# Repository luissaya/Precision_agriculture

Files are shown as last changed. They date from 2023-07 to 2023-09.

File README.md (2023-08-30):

# Precision Agriculture
Design of an IoT device for agriculture properties tracking.  
[Sensors](./docs/sensors.md)
## General Structure
The hole system is designed in two parts, the first is one *Gateway* that upload data to the cloud and the second is the *Node*. Various Nodes can feed the gateway with data from sensors.  
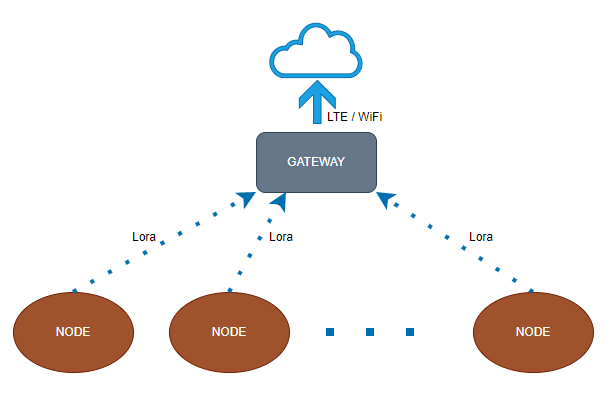
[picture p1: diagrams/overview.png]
overview

## Gateway
Receive the data from the Node and is preprocessed to be sent to the cloud through LTE, Ethernet or WiFi.
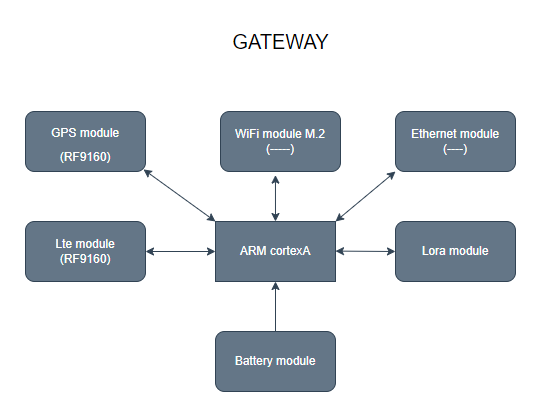
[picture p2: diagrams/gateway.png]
gateway

## [Node](./docs/Node.md)
Retrieve the data from sensors and send through Lora to the Gateway.
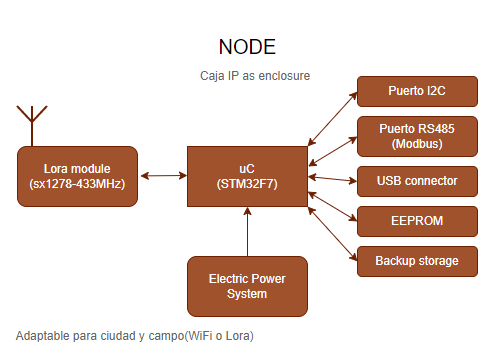
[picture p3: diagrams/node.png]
node
  
Note: *for indoor independent functionality the Lora module would be replaced for an WiFi module.*

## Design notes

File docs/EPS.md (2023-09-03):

# Electrical Power system
Design reference: [Quetzal](https://github.com/Quetzal-1-CubeSat-Team/quetzal1-hardware/tree/master/EPS)  
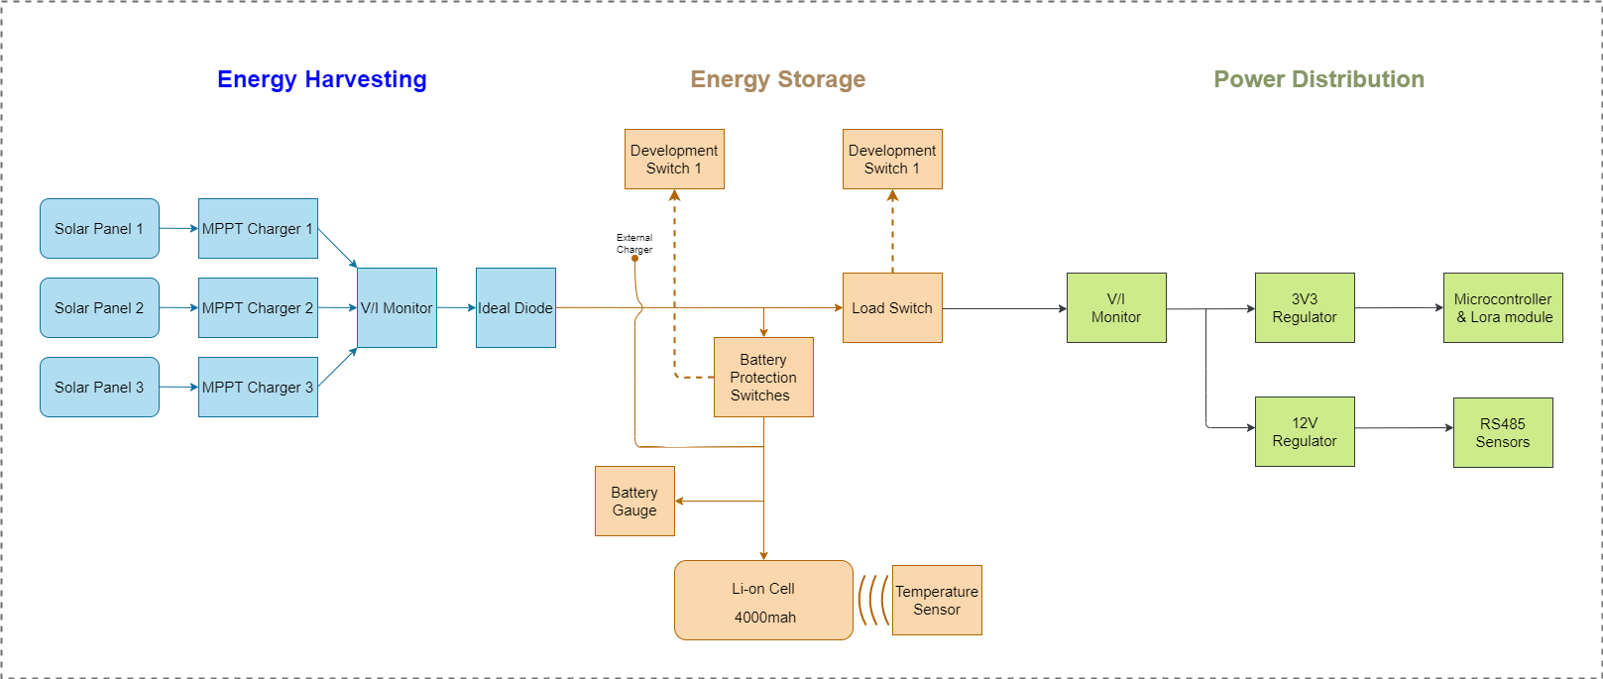
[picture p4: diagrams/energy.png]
energy
  
## Energy harvesting
* MPTT charger: for solar panels
* Voltage current monitor: for solar panels
* Ideal diode: supply current to *Energy storage*
  - Device: TC4352IMS#TRPBF - Low Voltage Ideal Diode Controller with Monitoring
  
## Energy storage
* Battery protection: limit current from solar panels
  - Device: TPS2551QDBVRQ1 - ADJUSTABLE CURRENT LIMITED POWER DISTRIBUTION SWITCH
* Battery monitoring: sense current from solar panels
  - Device: BQ27441DRZR-G1A - System-Side Impedance Track™ Fuel Gauge
  - operates with supplies from 2.9V to 18V
* Voltage protection: limit current that supply *Power distribution* 
  - Device: TPS2551QDBVRQ1 - ADJUSTABLE CURRENT LIMITED POWER DISTRIBUTION SWITCH
  - Adjustable Current-Limit: 100 mA to 1100 mA
  - Reverse Input-Output Voltage Protection
  - Operating Range: 2.5 V to 6.5 V
  - 15-kV ESD Protection (With External capacitance)
## Power distribution
* Voltage monitor: Sense the voltage that comes from of the battery.
* Voltage regulators:
  - 3.3 Volts: Supply energy for the microcontroller and general signal circuits.
  - 5 Volts: Supply energy for the I2C devices
  - 12 Volts: Supply energy for the RS485 devices
## Energy calculation
Maximum energy consumption:
- RS485 sensors: 0.5W(12V, 41.7mA / 5V, 100mA)
- I2C sensors: 0.1W(3.3V, 30.3mA), 0.6W(120mA, 5V)
- STM32F7 with all peripherals: 200mA, 3.3V
- Lora1278-C1 140mA, 3.3V
- ESP32-C3 350mA, 3.3V

Power energy of voltage regulator:
- 3.3V : 750mA <> 350 + 200 + 140 + 2x30.3
-   5V : 450mA <> 2x100 + 2x120 
-  12V : 130mA <> 3*41.7

Characteristics:
- Up to 3 RS485 sensors(up to 3 x 12V and 2 x 5V ): 1.5W
- Up to 2 I2C ( 3.3V or 5V): 0.2W/1.2W
- WiFi or Lora wireless communication: 1.15W/0.46W

Battery dimensioning:

WiFi|Configurations  | RS485 |  I2C  | Total Power(W)|
----|----------------|-------|-------|---------------|
----|  Max demand    |   3   | 2(5V) |    3.85       |
----|  All RS485     |   3   |   0   |    2.65       |
----|  All I2C       |   0   | 2(5V) |    2.35       |
----|Min demand RS485|   1   |   0   |    1.55       |
----| Min demand I2C |   0   |1(3.3V)|    1.35       |

Lora|Configurations  | RS485 |  I2C  | Total Power(W)|
----|----------------|-------|-------|---------------|
----|  Max demand    |   3   | 2(5V) |    3.16       |
----|  All RS485     |   3   |   0   |    1.96       |
----|  All I2C       |   0   | 2(5V) |    1.66       |
----|Min demand RS485|   1   |   0   |    0.86       |
----| Min demand I2C |   0   |1(3.3V)|    0.66       |

- power: 3.85W(5 sensors and wifi), 1W(1 sensor RS485 and Lora) 
- battery: 10AH(4.2V)= 42WH
- duration:  10.9hour / 42hour
- solar panel:

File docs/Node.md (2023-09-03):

## Node
Device in charge of collect data from sensors to be delivered to the Gateway throughout Lora protocol.  

Also this device can works independently using the WiFi interface to upload directly the data to the cloud.
## Overview
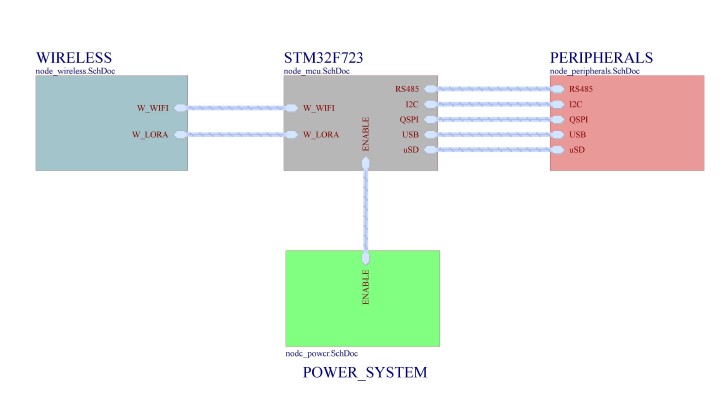
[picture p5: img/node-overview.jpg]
node-overview

## Microcontroller
  *STM32F723ZET6*  
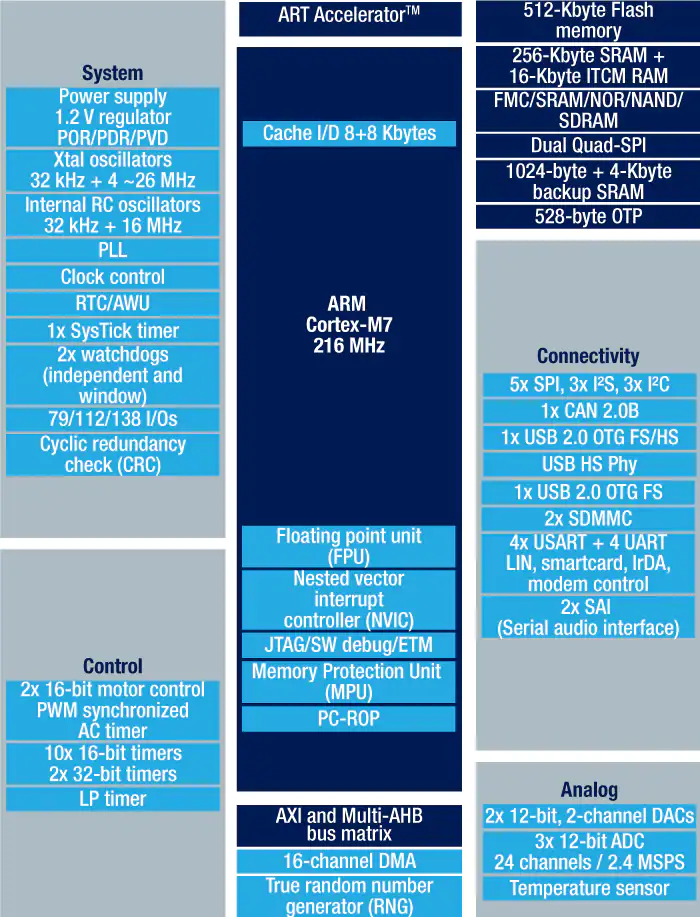
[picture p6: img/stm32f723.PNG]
STM32F7
  
- [Datasheet](https://www.st.com/resource/en/datasheet/stm32f722ic.pdf)
- Oscilators:  
  - 25 MHz: main
  - 32.768KHz: for 32bit
- Interfaces used:
  - SDMMC1: micro SD
  - QUADSPI_BK1: Flash memory 128Mbit
  - I2C1: I2C for sensors
  - OTG_HS: USB C connector
  - UART7: RS485 for sensors
  - UART4: WiFi microcontroller
  - I2C2: I2C for electrical power system
  - SWD: SWD connector

## Peripherals
- QSPI Flash memory 128Mbits
- RS485 interface
- microSD holder
- USB C connector
- SWD connector
- I2C connector

## Wireless
- ESP32_C3:
  - USB C connector
  - Reset and Boot buttons
- LORA_1278_433MHz:
  - SMA Connector Receptacle

## [Electrical Power system](../docs/EPS.md)
energy

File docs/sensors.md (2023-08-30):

# Sensors

## Air quality
- HKNA Air quality detector WIFI RS485 (RS-MG111-*-1)  
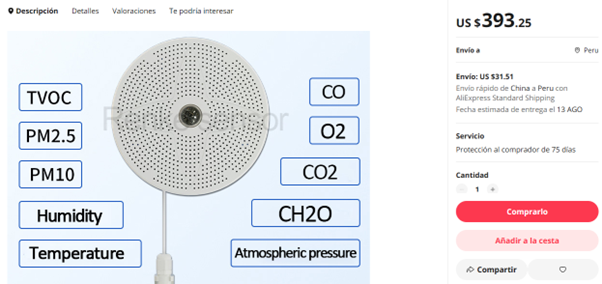
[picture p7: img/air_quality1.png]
  
  [Provider](https://es.aliexpress.com/item/1005004700732022.html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)

- ComWinTop Air quality Sensor RS485 (CWT-SAQ-X-CH)  
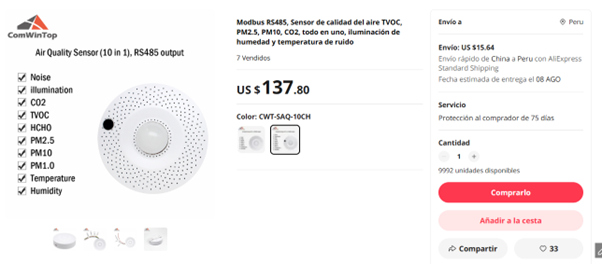
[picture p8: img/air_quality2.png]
  
  [Provider](https://es.aliexpress.com/item/1005003202262914.html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)

## Soil
- ComWinTop Soil Sensor RS485 (CWT-soil)  
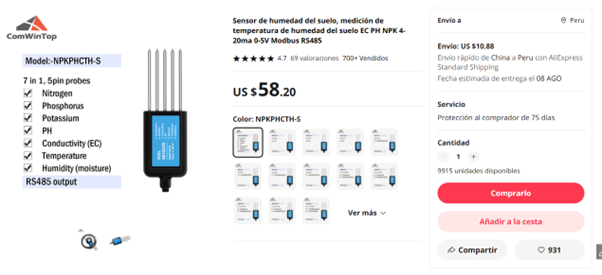
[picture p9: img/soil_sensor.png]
  
  [Provider](https://www.aliexpress.com/item/1005001524845572.html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)

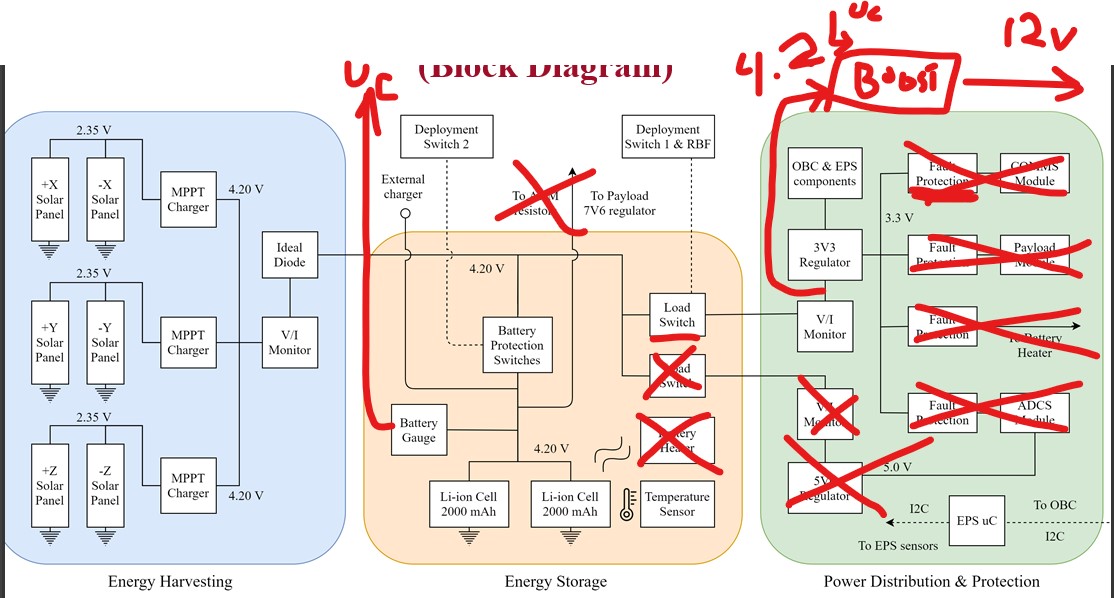
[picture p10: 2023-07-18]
diagrams/diagrama_sketch.jpg

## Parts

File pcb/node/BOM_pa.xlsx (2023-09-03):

 |  |  | xxxx xxxx xxxxx xxPCS BOM (Sample Bill of Materials)
Item # | *Designator | *Qty | Manufacturer | *Mfg Part # | Description / Value | *Package/Footprint | Type | Your Instructions / Notes | Datasheet | Source | unit price | Total
1 |  | 1 | Winbond Elec | W25Q128JVEIQ TR | FLASH - NOR Memory IC 128Mbit SPI - Quad I/O, QPI, DTR 133 MHz 8-WSON (8x6) | WSON (8x6) | SMD |  | https://datasheet.lcsc.com/lcsc/2304140030_Winbond-Elec-W25Q128JVEIQ-TR_C2456297.pdf | https://www.lcsc.com/product-detail/NAND-FLASH_Winbond-Elec-W25Q128JVEIQ-TR_C2456297.html | $1.47
2 |  | 1 | SHOU HAN | TF PUSH | -20℃~+90℃ 2mm Deck MicroSD card (TF card) Self bomb SMD SD Card Connectors | SMD SD Card Connector | SMD |  | https://datasheet.lcsc.com/lcsc/1912111437_SHOU-HAN-TF-PUSH_C393941.pdf | https://www.lcsc.com/product-detail/span-style-background-color-ff0-SD-span-span-style-background-color-ff0-Card-span-Connectors_SHOU-HAN-TF-PUSH_C393941.html | $0.05
 |  |  | DEALON | USB-TYPE-C-019 | 3A 1 Surface Mount 16P Female -25℃~+85℃ Type-C SMD USB Connectors | SMD 16P female | SMD |  | https://datasheet.lcsc.com/lcsc/2201121330_DEALON-USB-TYPE-C-019_C2927039.pdf | https://www.lcsc.com/product-detail/span-style-background-color-ff0-USB-span-Connectors_DEALON-USB-TYPE-C-019_C2927039.html | $0.45
 |  |  | Espressif Systems | ESP32-C3-WROOM-02-N4 | Bluetooth, WiFi 802.11b/g/n, Bluetooth v5.0 Transceiver Module 2.4GHz PCB Trace Surface Mount | 19-SMD Module | SMD |  | https://www.digikey.com/en/products/detail/espressif-systems/ESP32-C3-WROOM-02-N4/14553031 | https://www.espressif.com/sites/default/files/documentation/esp32-c3-wroom-02_datasheet_en.pdf | $1.95
 |  |  | Analog Devices Inc. | LTC2854IDD#TRPBF | 1/1 Transceiver Half RS422, RS485 10-DFN (3x3) | 10-WFDFN Exposed Pad | SMD |  | https://datasheet.lcsc.com/lcsc/2008261939_Analog-Devices-LTC2854IDD-TRPBF_C730043.pdf | https://www.lcsc.com/product-detail/RS-485-RS-422-ICs_Analog-Devices-LTC2854IDD-TRPBF_C730043.html | $4.89
 |  |  | STMicroelectronics | STM32F723ZET6 | 512KB 1.7V~3.6V ARM-MSeries 256KB 216MHz FLASH 112 LQFP-144(20x20) Microcontroller Units | LQFP-144(20x20) | SMD |  | https://datasheet.lcsc.com/lcsc/2107091826_STMicroelectronics-STM32F723ZET6_C1340305.pdf | https://www.lcsc.com/product-detail/Microcontroller-Units-MCUs-MPUs-SOCs_STMicroelectronics-STM32F723ZET6_C1340305.html | $9.60
 |  |  | G-NiceRF | lora1278-C1-433MHz | SMD,16x16mm LoRa Modules | SMD,16x16mm | SMD |  | https://datasheet.lcsc.com/lcsc/2204251600_G-NiceRF-lora1278-C1-433MHz_C3001529.pdf | https://www.lcsc.com/product-detail/span-style-background-color-ff0-LoRa-span-Modules_G-NiceRF-lora1278-C1-433MHz_C3001529.html | $4.94
 |  |  | HOAUC | HYCW10-SMAW5365-1350B | Plugin RF Connectors / Coaxial Connectors | Plugin | Through Hole |  | https://datasheet.lcsc.com/lcsc/2212060930_HOAUC-HYCW10-SMAW5365-1350B_C5301852.pdf | https://www.lcsc.com/product-detail/RF-Connectors-Coaxial-Connectors_HOAUC-HYCW10-SMAW5365-1350B_C5301852.html | $0.27
 |  |  | MikroElektronika | MIKROE-2352 | 433MHz LoRa Whip, Right Angle RF Antenna 1.5dBi SMA Male Connector Mount | SMA Male | Connector Mount |  | https://media.digikey.com/pdf/Data%20Sheets/MikroElektronika%20PDFs/DL433M-R1-02_(MIKROE-2352).pdf | https://www.digikey.com/en/products/detail/mikroelektronika/MIKROE-2352/6165545 | $6.90
 |  |  | GOODWORK | SMBJ7.0CA | 12V 7.78V 7V SMB(DO-214AA) TVS | SMB(DO-214AA) | SMD |  | https://datasheet.lcsc.com/lcsc/2012311806_GOODWORK-SMBJ7-0CA_C908838.pdf | https://www.lcsc.com/product-detail/TVS_GOODWORK-SMBJ7-0CA_C908838.html | $0.02
 |  |  | ElecSuper | CDSOT23-SM712-ES | 2 Bi-Directional SOT-23(TO-236) ESD Protection Devices | SOT-23(TO-236) | SMD |  | https://datasheet.lcsc.com/lcsc/2210171700_ElecSuper-CDSOT23-SM712-ES_C5199207.pdf | https://www.lcsc.com/product-detail/ESD-Protection-Devices_ElecSuper-CDSOT23-SM712-ES_C5199207.html | $0.04
 |  |  | STMicroelectronics | ECMF02-4CMX8 | QFN-8(1.2x2.5) Common Mode Filters | QFN-8(1.2x2.5) | SMD |  | https://datasheet.lcsc.com/lcsc/2105241335_STMicroelectronics-ECMF02-4CMX8_C717678.pdf | https://www.lcsc.com/product-detail/Common-Mode-Filters_STMicroelectronics-ECMF02-4CMX8_C717678.html | $0.50
Need a quick and accurante quote? Need an efficient production? Please read SMT Ordering Necessary Files & Info in 1 minute. Thank you very much! (https://www.pcbway.com/smt_ordering_guide.html)
Click for Instructions on How to Create a BOM (https://www.pcbway.com/blog/PCB_Assembly/How_to_Build_a_BOM__Bill_Of_Materials_.html)

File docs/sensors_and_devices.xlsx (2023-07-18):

Item | Quantity | Name | Description | Aliexpress | Unit price | Total | Digikey | unit price2 | Total2
1 | 1 | Sensor de suelo 7 en 1 | RS485 4-20mA Soil Temperature Humidity Moisture Conductivity EC PH Sensor | https://es.aliexpress.com/item/1005001524845572.html?curPageLogUid=Ekkg42sYhgAW | $69.08 | $69.08 |  |  | $0.00
2 | 1 | NRF9160-DK | - nRF9160 Transceiver 700MHz ~ 2.2GHz Evaluation Board | https://es.aliexpress.com/item/4000927307221.html?curPageLogUid=v209Gw2tp1sR | $212.00 | $212.00 | https://www.digikey.com/en/products/detail/nordic-semiconductor-asa/NRF9160-DK/9740721 | $155.00 | $155.00
3 | 1 | NUCLEO-WL55JC1 | STM32WB STM32WL55 Transceiver; LoRa® 865MHz ~ 928MHz Evaluation Board | https://es.aliexpress.com/item/1005002049032719.html?curPageLogUid=QDGNtImDrfOr | $75.92 | $75.92 | https://www.digikey.com/en/products/detail/stmicroelectronics/NUCLEO-WL55JC1/13893870 | $42.00 | $42.00
4 | 2 | LILYGO TTGO LoRa32 | LILYGO®TTGO-módulo inalámbrico LoRa32 V2.1, Versión 1,6, 433/868/915Mhz, ESP32 LoRa OLED, tarjeta SD de 0,96 pulgadas, Bluetooth, WIFI, ESP-32 SMA | https://es.aliexpress.com/item/32872078587.html?gatewayAdapt=gloMsite2espPcglo2esp#nav-review | $25.25 | $50.50 |  |  | $0.00
 |  | Ra-01 LoRa SX1278 |  |  | $3.17 | $0.00 |  |  | $0.00

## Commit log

2023-07-18 init: start
    [sensors_and_devices.xlsx]
2023-07-21 energy protection
    [power_energy_storage.SchDoc]
2023-07-21 modify template
    [node.PrjPcb, node_connections.SchDoc, node_index.SchDoc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]
2023-08-30 fix: readme and docs
    [BOM_pa.xlsx, RNM0015A.stp, TPS63070RNMT.PcbLib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]
2023-08-31 update: docs
    [node.PrjPcb, node_index.SchDoc, node_mcu.SchDoc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]
2023-09-03 update: docs and pcb
    [BOM_pa.xlsx, power_voltage_regulators.SchDoc]
